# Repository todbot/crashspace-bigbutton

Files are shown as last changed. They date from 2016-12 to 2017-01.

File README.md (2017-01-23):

# crashspace-bigbutton



Firmware and schematics for the [CrashSpace](https://blog.crashspace.org/)
"BigButton" hardware interface to https://crashspacela.com/sign/

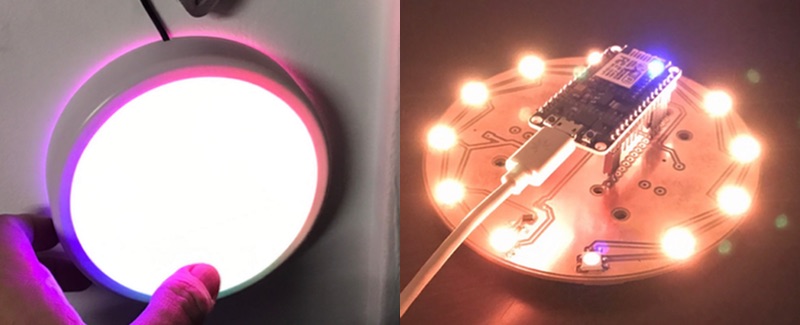
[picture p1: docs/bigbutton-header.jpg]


At [CrashSpace](https://blog.crashspace.org/) we have a publicly-viewable
"sign" at https://crashspacela.com/sign/ to let members know when the
space is open. This sign page is updated by a big button in the front
room.  Press it, the sign webpage updates, and you've promised to be
in the space for an hour.

This repo is documentation of the new BigButton hardware that was installed
at CrashSpace in Jan 2017.

## Table of Contents

* [Functionality](#functionality)
* [In use](#in-use)
* [Implementation](#implementation)
 * [Implementation - Hardware](#implementation---hardware)
    * [Converting 3v3 ESP8266 output for WS2812 / Neopixel  LEDs](#converting-3v3-esp8266-output-for-ws2812--neopixel--leds)
    * [Othermill design considerations](#othermill-design-considerations)
 * [Implementation - Firmware](#implementation---firmware)
    * [ArduinoJson is awesome](#arduinojson-is-awesome)
    * [CrashSpace sign server JSON API](#crashspace-sign-server-json-api)

## Functionality

* The BigButton consists of a pushbutton and a ring of LEDs
* The user pushes the button to signify they're at the space
* The LED ring displays whether or not CrashSpace is "open" or "closed"
* The LED ring visually shows a count down from 60 minutes,
  giving a rough indication of time left
* Pushing the button sends an HTTP request to the CrashSpace "sign" server
   at https://crashspacela.com/sign/
* (new!) The button periodically fetches a JSON feed from the
  sign server, getting time left and whether space is open or not.
  This allows for multiple buttons.

## In use

  * Button is pulsing ORANGE: CrashSpace is closed
  * Push Button.  Button spins a RAINBOW for a second or two, then
  * Button is pulsing TEAL: CrashSpace is open
  * Button counts down my extinguishing TEAL LEDs in an arc
  * Button flashing RED: Internet is down

## Implementation

The original BigButton implementation was an Arduino Uno with WS2812 LEDs inside a
large taplight tied to a Linux netbook for WiFi connectivity.
An upgrade button created several years late used an early version of the
Particle Photon Internet Button kit in a custom 3d printed enclosure.

This version of BigButton uses an
[ESP82166 Wemos D1 mini](https://www.wemos.cc/product/d1-mini.html)
WiFi board mounted to a custom carrier board containing 12 WS2812 LEDs.
It uses the [ESP8266 Arduino core](https://github.com/esp8266/Arduino/)
to run an Arduino sketch.

### Implementation - Hardware

The hardware implementation is pretty straight forward.
The Wemos D1 mini ESP8266 board does all the work.
The input is a single button and the output is a string of WS2812 LEDs.

The schematic and layout for the carrier board is:

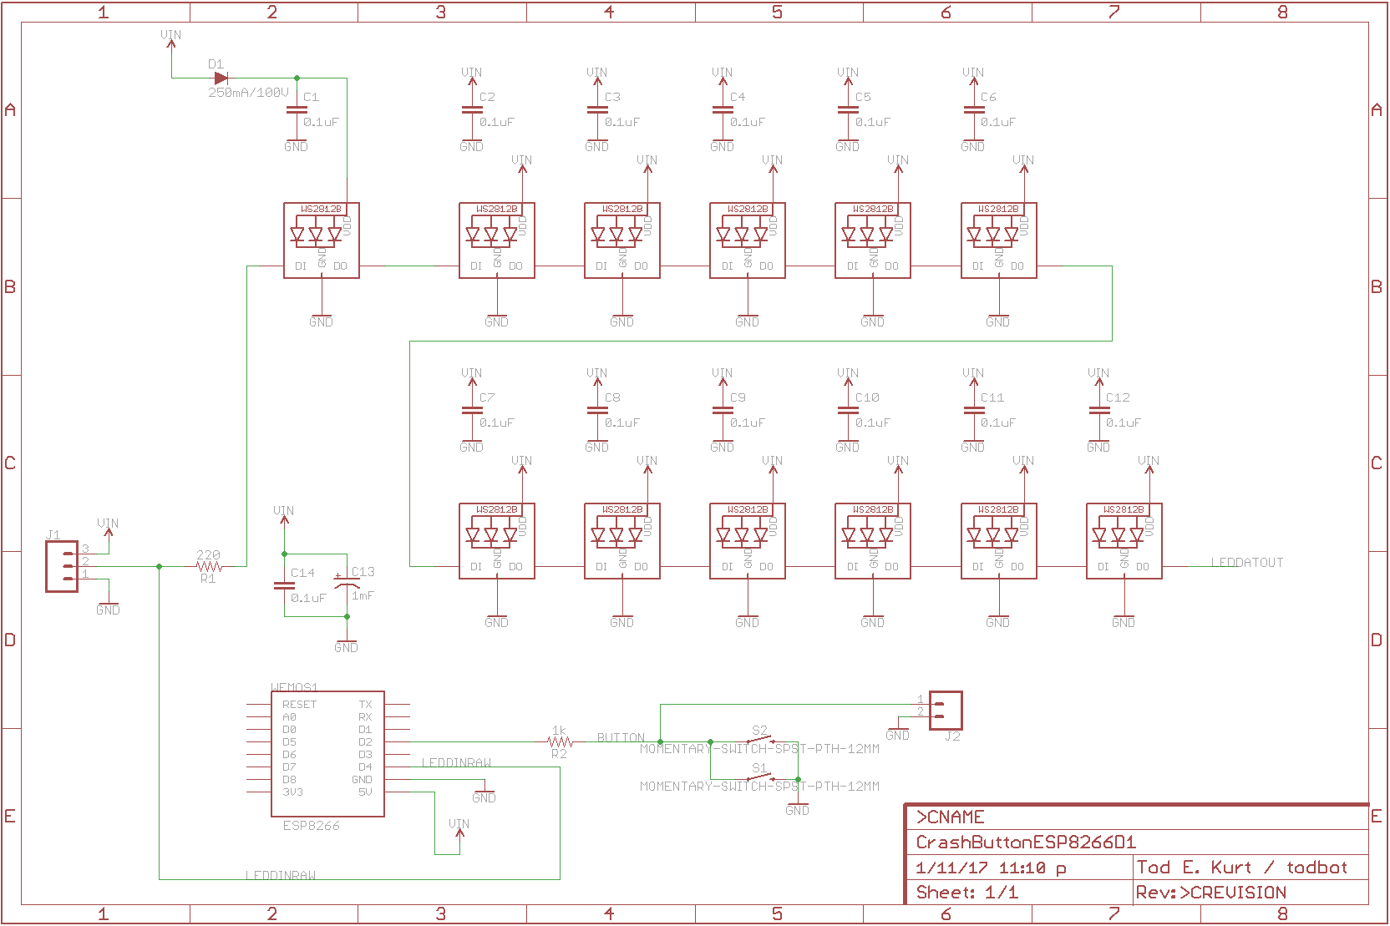
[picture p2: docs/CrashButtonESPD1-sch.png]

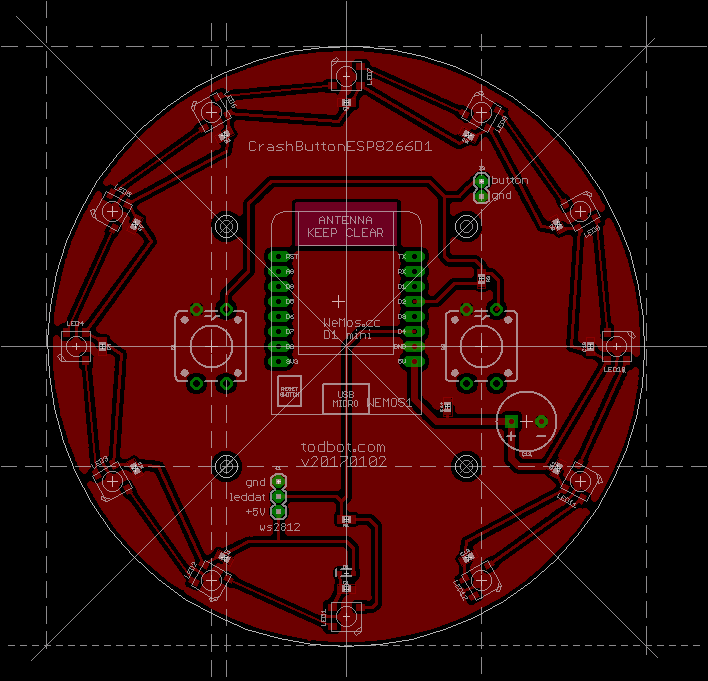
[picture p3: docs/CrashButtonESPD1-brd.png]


Eagle format versions of these are in the [schematic](./schematic) folder.

#### Converting 3v3 ESP8266 output for WS2812 / Neopixel  LEDs

One interesting thing about the schematic how the ESP8266 (a 3v3 device)
manages to control 5V WS2812/Neopixel LEDs.  Some WS2812s can be driven by 3v3 logic HIGH, but it's iffy.  The standard solution is a level-shifter buffer to convert 3v3 HIGH to 5V HIGH.

The technique used on this board, however, is to create a "sacrificial" LED that powered not by 5V but by a stepped-down voltage from a standard signal diode
(with its 0.7V voltage drop).  This creates an approx. 4.3V power source that is high enough to drive the LED but brings its concept of logic HIGH (>70% of Vcc) down to what a 3v3 device will output.  Basically, we're building a
special intermediary power supply for a single LED.
The rest of the WS2812 LEDs are driven by 5V.

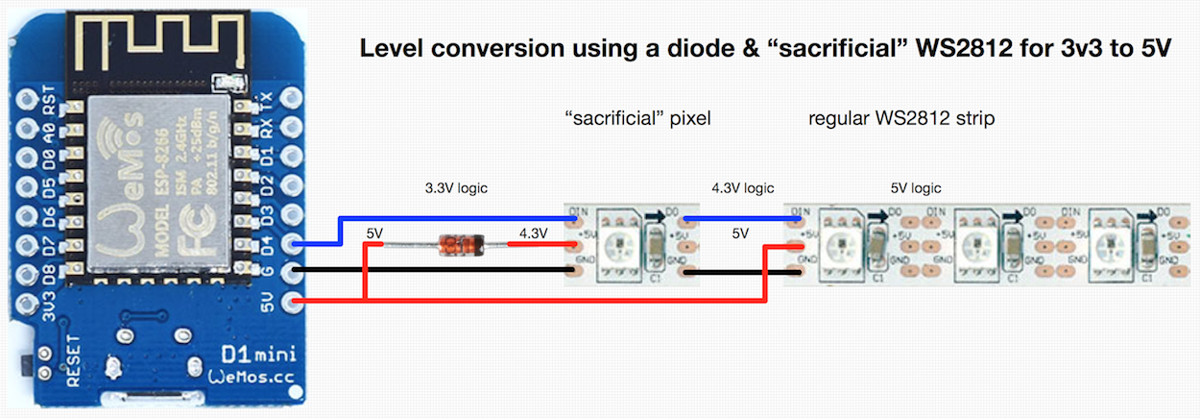
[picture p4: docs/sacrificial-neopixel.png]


#### Othermill design considerations

I wanted this board to be millable on an Othermill, so that meant adopting slightly different PCB design techniques.  There are a few reasons for this. For instance, because this board has no soldermask, I want to maximize spacing between copper traces.  Also, I would like to minimize the use of endmills smaller than 1/32" because they are fragile and take a long time to mill.  Thus, the techniques I use are:

* Increase trace width 16 mil (0.016")
* Add ground plane, set its Polygon->Isolate value to 32 mil (0.032")
* Single-sided only design (or minimize back-side traces)
* Space components out to enable easy soldering

The result is below. The Wemos D1 Mini ESP8266 board is mounted on the
backside of the board to minimize its impact on light output.  
The board is mounted on standoffs which are screwed into the modified
taplight. The taplight's switch is reused as the button input.

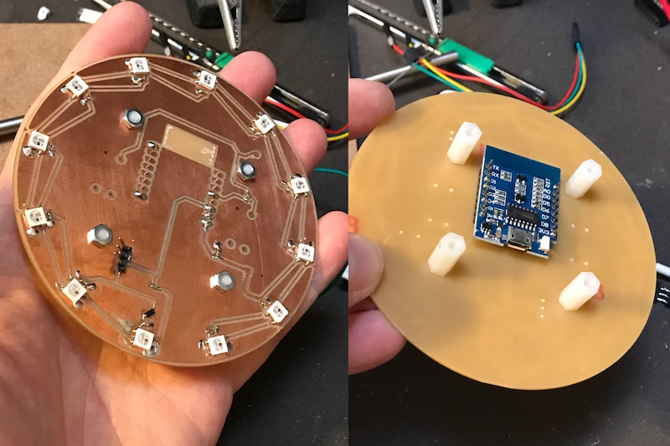
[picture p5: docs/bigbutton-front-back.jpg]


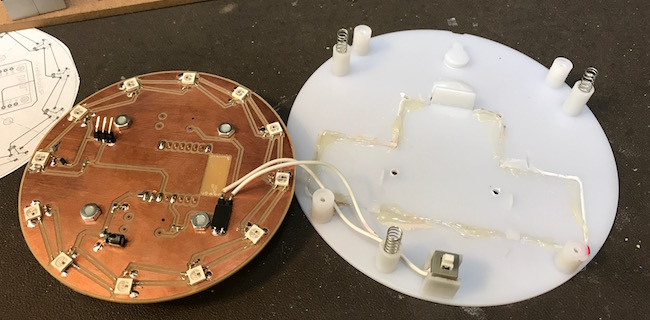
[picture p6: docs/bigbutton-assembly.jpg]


### Implementation - Firmware

The ESP8266 runs the ["CrashButtonESP"](./CrashButtonESP/) Arduino sketch.

#### ArduinoJson is awesome

The sketch relies on the ArduinoJson library.
With it you can easily parse and use JSON data structures.
And with its magical use of C++ operator-overloading you can have code
like this:

```c++
// jsonstr = '{"is_open":false,"minutes_left":-920.45,"button_presses":[]}'
JsonObject& root = jsonBuffer.parseObject(jsonstr);
bool is_open        = root["is_open"];
double minutes_left = root["minutes_left"];
```

#### CrashSpace sign server JSON API

To enable the button to report real open status
(and not just a dumb countdown), the sign server API at
https://crashspacela.com/sign/
has been updated with a JSON output mode.  There are two versions
of JSON output, picked with the `output` query arg:
* `jsonmin` - "minimal" version with just open status and minutes left
* `json`  - full version that gives a list of recent button presses

The Button uses the minimal one.  Both are shown below:

```json
% curl 'https://crashspacela.com/sign/?output=jsonmin'
{"is_open":false,"minutes_left":-920.45,"button_presses":[]}
```

```json
% curl 'https://crashspacela.com/sign/?output=json'
{
    "is_open": false,
    "minutes_left": -919.43333333333,
    "button_presses": [
        {
            "type": "update",
            "id": "crashbutton1",
            "msg": "Someone is at the space!",
            "diff_mins_max": 60,
            "description": "crashbutton1 - update - 60 mins.",
            "date": "Wed, 11 Jan 2017 21:38:03 -0800",
            "date_epoch": "1484199483"
        },
        {
            "type": "update",
            "id": "crashbutton1",
            "msg": "Someone is at the space!",
            "diff_mins_max": 60,
            "description": "crashbutton1 - update - 60 mins.",
            "date": "Wed, 11 Jan 2017 20:00:00 -0800",
            "date_epoch": "1484193600"
        },
        {
            "type": "update",
            "id": "crashbutton1",
            "msg": "Someone is at the space!",
            "diff_mins_max": 60,
            "description": "crashbutton1 - update - 60 mins.",
            "date": "Wed, 11 Jan 2017 19:16:26 -0800",
            "date_epoch": "1484190986"
        }
    ]
}
```

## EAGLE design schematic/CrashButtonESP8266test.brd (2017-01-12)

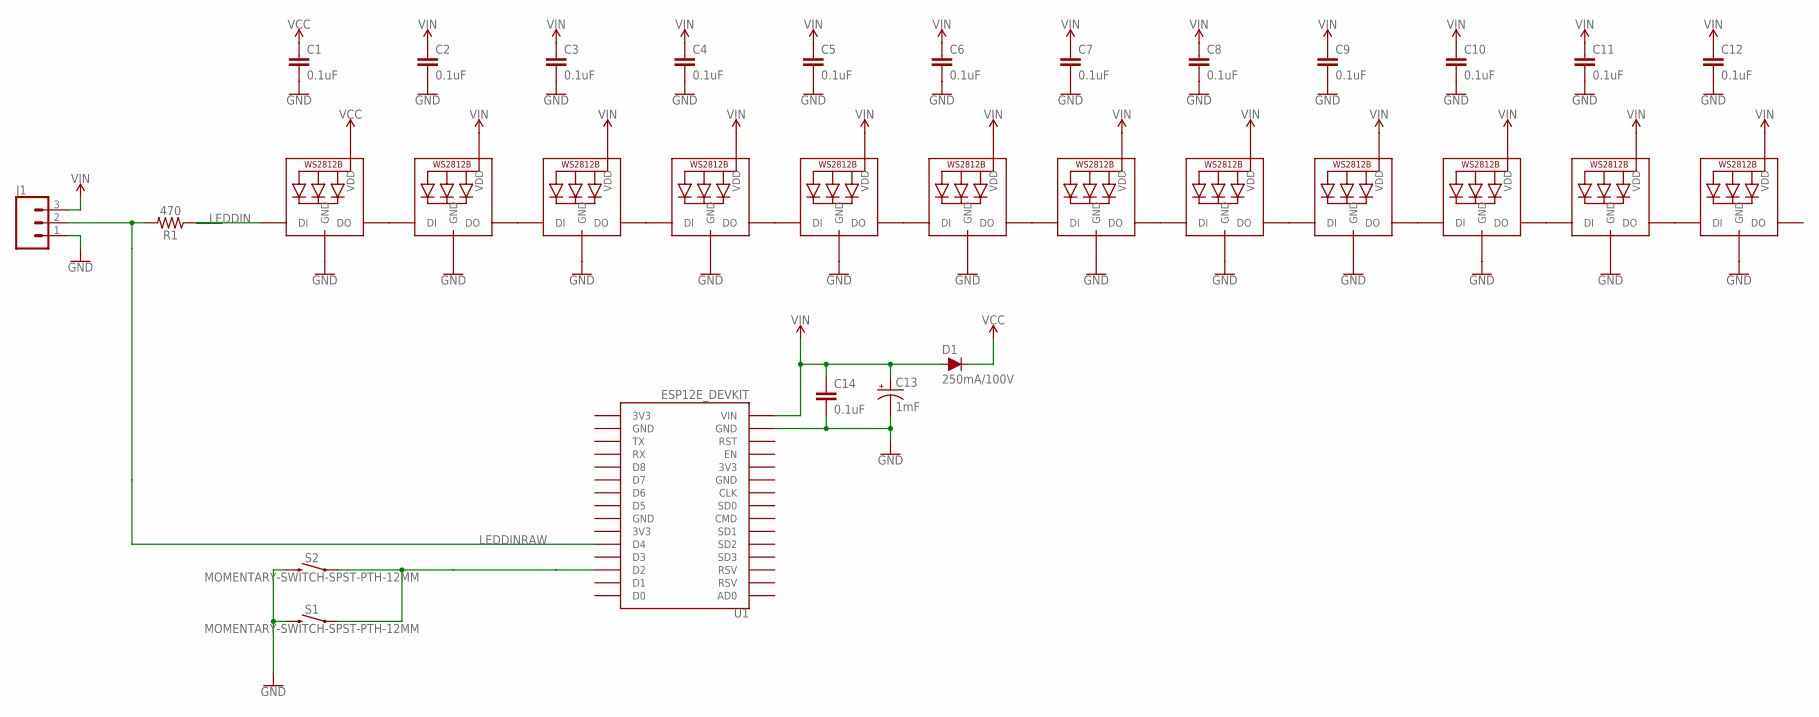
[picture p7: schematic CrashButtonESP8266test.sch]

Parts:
C1, C2, C3, C4, C5, C6, C7, C8, C9, C10, C11, C12, C14: 0.1uF; 0603
C13: 1mF; CPOL-RADIAL-5MM-10MM
D1: 250mA/100V; SOD-323
J1: CONN_03; 1X03
LED1, LED2, LED3, LED4, LED5, LED6, LED7, LED8, LED9, LED10, LED11, LED12: WS2812B5050; WS2812B
R1: 470; 0603
S1, S2: MOMENTARY-SWITCH-SPST-PTH-12MM; TACTILE_SWITCH_PTH_12MM
U1: ESP12E_DEVKIT

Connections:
GND: C1.2, C2.2, C3.2, C4.2, C5.2, C6.2, C7.2, C8.2, C9.2, C10.2, C11.2, C12.2, C13.-, C14.2, J1.1, LED1.3-GND (GND), LED2.3-GND (GND), LED3.3-GND (GND), LED4.3-GND (GND), LED5.3-GND (GND), LED6.3-GND (GND), LED7.3-GND (GND), LED8.3-GND (GND), LED9.3-GND (GND), LED10.3-GND (GND), LED11.3-GND (GND), LED12.3-GND (GND), S1.3 (2), S2.3 (2), U1.GND@1 (GND)
LEDDIN: LED1.4-DIN (DI), R1.1
LEDDINRAW: J1.2, R1.2, U1.D4
unnamed: LED1.2-DOUT (DO), LED2.4-DIN (DI)
unnamed: LED2.2-DOUT (DO), LED3.4-DIN (DI)
unnamed: LED3.2-DOUT (DO), LED4.4-DIN (DI)
unnamed: LED4.2-DOUT (DO), LED5.4-DIN (DI)
unnamed: LED5.2-DOUT (DO), LED6.4-DIN (DI)
unnamed: LED6.2-DOUT (DO), LED7.4-DIN (DI)
unnamed: LED8.2-DOUT (DO), LED9.4-DIN (DI)
unnamed: LED9.2-DOUT (DO), LED10.4-DIN (DI)
unnamed: LED10.2-DOUT (DO), LED11.4-DIN (DI)
unnamed: S1.1, S2.1, U1.D2
unnamed: LED7.2-DOUT (DO), LED8.4-DIN (DI)
unnamed: LED11.2-DOUT (DO), LED12.4-DIN (DI)
VCC: C1.1, D1.C, LED1.1-VDD (VDD)
VIN: C2.1, C3.1, C4.1, C5.1, C6.1, C7.1, C8.1, C9.1, C10.1, C11.1, C12.1, C13.+, C14.1, D1.A, J1.3, LED2.1-VDD (VDD), LED3.1-VDD (VDD), LED4.1-VDD (VDD), LED5.1-VDD (VDD), LED6.1-VDD (VDD), LED7.1-VDD (VDD), LED8.1-VDD (VDD), LED9.1-VDD (VDD), LED10.1-VDD (VDD), LED11.1-VDD (VDD), LED12.1-VDD (VDD), U1.VIN

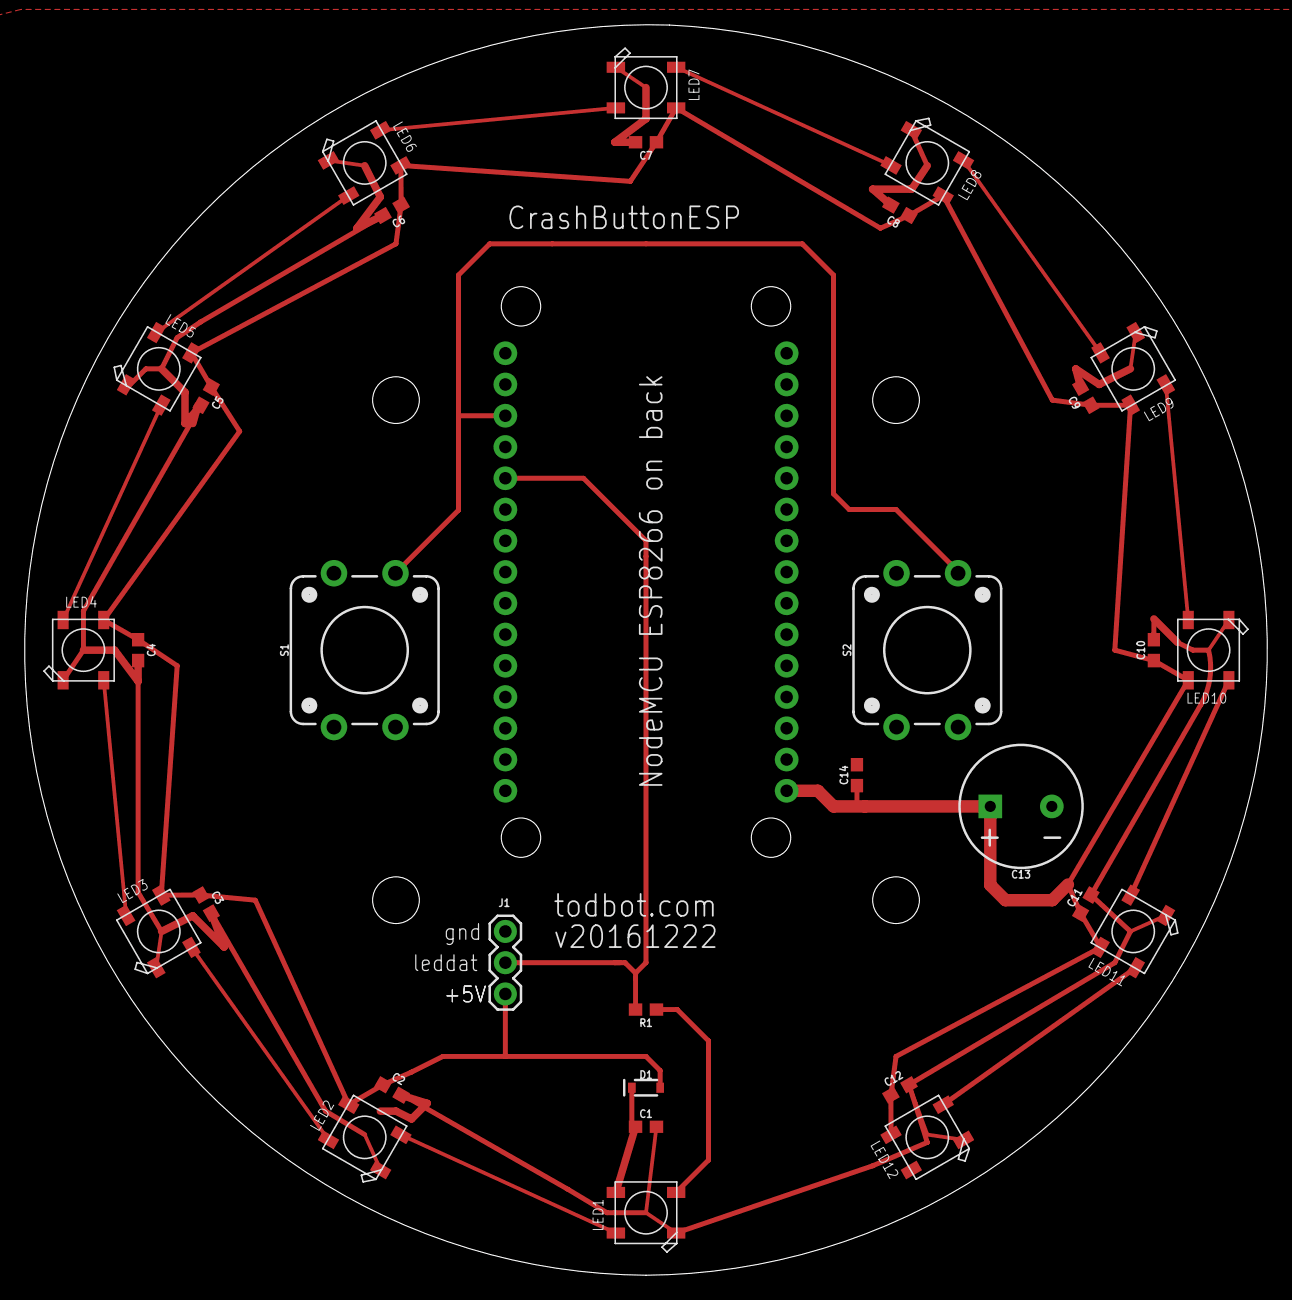
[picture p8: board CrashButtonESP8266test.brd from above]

Board: 2 copper layers, 101.0 x 101.6 mm, 32 parts (1 on the bottom side), 17 nets.

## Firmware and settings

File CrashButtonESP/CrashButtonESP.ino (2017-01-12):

/**
 *  CrashButtonESP - ESP8266-based BigButton for CrashSpace
 *
 *  Tod E. Kurt / http://todbot.com/
 *  
 *  Set Board to be "Wemos D1 R2 & mini"
 *  
 *  Requires libraries:
 *  - FastLED 3.1+ - https://github.com/FastLED/FastLED
 *  - ArduinoJson - https://github.com/bblanchon/ArduinoJson
 *  - ESP8266 Arduino core - https://github.com/esp8266/Arduino/
 *  
 **/

#include <Arduino.h>

#include <ESP8266WiFi.h>
#include <ESP8266WiFiMulti.h>
#include <ESP8266HTTPClient.h>
#include <Ticker.h>  // part of ESP8266 Arduino core

//#define FASTLED_ALLOW_INTERRUPTS 0
#define FASTLED_ESP8266_RAW_PIN_ORDER
#include <FastLED.h>
FASTLED_USING_NAMESPACE

#include <ArduinoJson.h>

#include "CrashButtonConfig.h"


// What mode are we in?  These are the allowed ones
typedef enum ButtonModes {
    MODE_UNKNOWN = 0,
    MODE_STARTUP,      // not joined AP yet, 
    MODE_CLOSED,       // "closed" button hasn't been pressed in a while, color: yellow 
    MODE_PRESSED,      // user pressed button, but before app has fetched state
    MODE_PRESSED_GOOD, // user pressed button, but before app has fetched state
    MODE_OPEN,         // shows current open time 
    MODE_ERROR         // error of some kind, flash error, color: red
} ButtonMode;

typedef enum LedModes {
    MODE_OFF = 0,
    MODE_PRESET,
    MODE_SOLID,
    MODE_SINELON,
    MODE_BREATHE,
    MODE_SECTOR,
    MODE_SECTORBREATHE,
    MODE_RAINBOW
} LedMode;

const int rainbowTime = 5 * 1000;  // duration of rainbow when pressing button

const int fetchMillis = 15 * 1000;  // how often API URL is checked
uint32_t lastFetchMillis = 0;

const uint32_t buttonCheckMillis = 60 * 1000; // min time between valid presses
uint32_t lastButtonCheckTime;
int lastButtonState; // state of last button (if using pressIsToggle)
uint32_t buttonPressTime = 0;

const uint8_t ledUpdateMillis = 50; // how often LEDs are updated

int badCount;
int maxBadCount = 5;    // how many bad events to become an error light
const uint32_t badMillis = 30 * 1000; // time between bad checks 
uint32_t lastBadMillis = 0;

// args for ledMode, basically, hmmm.
uint8_t ledHue = 0; // rotating "base color" used by many of the patterns
int ledSpeed = 100;
int ledCnt = NUM_LEDS;
int ledRangeL = 0;
int ledRangeH = 255;

CRGB leds[NUM_LEDS];

ButtonMode buttonMode = MODE_STARTUP;
LedMode ledMode = MODE_OFF;

Ticker ledticker;
ESP8266WiFiMulti WiFiMulti;


//
void setup()
{
    Serial.begin(115200);
    //Serial.setDebugOutput(true);
    //WiFi.disconnect(true);   // delete old config
    //WiFi.setAutoConnect( false );
 
    Serial.println("\nCrashButtonESP: " BUTTON_ID );
    delay(1500);    
    Serial.println("WiFi config:");
    WiFi.printDiag(Serial);

    pinMode( BUTTONPIN, INPUT_PULLUP);
    lastButtonState = digitalRead( BUTTONPIN );
    
    FastLED.addLeds<WS2812, LEDPIN, GRB>(leds, NUM_LEDS).setCorrection(TypicalLEDStrip);
    FastLED.setBrightness( brightnessDefault );
    fill_solid(leds, NUM_LEDS, CRGB(55, 0, 55));
    FastLED.show();
    
    for (uint8_t t = 4; t > 0; t--) {
        Serial.printf("[setupa] waiting %d...\n", t);
        Serial.flush();
        delay(800);
    }
    
    WiFiMulti.addAP(wifiSSID, wifiPasswd);
    
    ledticker.attach_ms( ledUpdateMillis, ledUpdate );

    Serial.println("[setup] done");
}

//
void loop()
{
    // wait for WiFi connection
    int rc = WiFiMulti.run();
    if ( (rc == WL_CONNECTED) ) {
        fetchJson();
    } 
    else {
        badCount++;
        Serial.print("WiFi not connected: "); Serial.println(rc);
        WiFi.printDiag(Serial);
        delay(1000); // delay still services background tasks for WiFi connect
    }
    
}

// Convert app state to LED commands
void buttonModeToLedMode() 
{
    if( buttonMode == MODE_STARTUP ) { 
        ledHue = 192; 
        ledMode = MODE_BREATHE;
        ledSpeed = 100;
        ledRangeL = 0;
        ledRangeH = 155;
    }
    else if( buttonMode == MODE_CLOSED ) {
        ledHue = 64; // yellow
        ledMode = MODE_BREATHE;
        ledCnt = NUM_LEDS;
        ledSpeed = 15;
        ledRangeL = 100;
        ledRangeH = 255;
    }
    else if( buttonMode == MODE_PRESSED ) { 
        ledMode = MODE_RAINBOW;
        ledCnt = NUM_LEDS;
        ledSpeed = millis() / 5;
        if( !buttonPressTime ) { 
            buttonPressTime = millis();
        } else {  // HACK FIXME: this whole buttonMode to ledMode idea not very good
            if( (millis() - buttonPressTime) > rainbowTime ) {
                //Serial.println("DOING THE HACK!");
                buttonMode = MODE_OPEN;
            }
        }
    }
    else if( buttonMode == MODE_PRESSED_GOOD ) { 
        ledMode = MODE_RAINBOW;
        ledCnt = NUM_LEDS;
        ledSpeed = millis() / 10;
    }
    else if( buttonMode == MODE_OPEN ) {
        ledHue = 128; // aqua
        ledMode = MODE_SECTORBREATHE;
        // ledCnt set elsewhere
        ledSpeed = 15;
        ledRangeL = 100;
        ledRangeH = 255;        
    }
    else if( buttonMode == MODE_ERROR ) {
        ledMode = MODE_BREATHE;
        ledHue = 0;
        ledCnt = NUM_LEDS;
        ledSpeed = 120;
        ledRangeL = 0;   // brightness low
        ledRangeH = 100; // brightness high
    }
}

// called periodically from Ticker
void ledUpdate()
{
    buttonCheck();
    
    buttonModeToLedMode();

    errorDetect();
    
    if( ledMode == MODE_OFF ) {
        fadeToBlackBy( leds, NUM_LEDS, 255);
    }
    else if( ledMode == MODE_SOLID ) {
        fill_solid( leds, ledCnt, CHSV(ledHue, 255, 255) );
    }
    else if( ledMode == MODE_SECTOR ) {
        fill_solid( leds, NUM_LEDS, 0 );
        fill_solid( leds, ledCnt, CHSV(ledHue, 255, 255) );
    }
    else if( ledMode == MODE_BREATHE ) {
        int breathe = beatsin8( ledSpeed, ledRangeL, ledRangeH);
        fill_solid( leds, NUM_LEDS, 0 );
        fill_solid( leds, ledCnt, CHSV(ledHue, 255, breathe) );
    }
    else if( ledMode == MODE_SECTORBREATHE ) { 
        int breathe = beatsin8( ledSpeed, ledRangeL, ledRangeH);        
        fill_solid( leds, NUM_LEDS, 0 );
        fill_solid( leds, ledCnt, CHSV(ledHue, 255, breathe) );
        if( ledCnt < NUM_LEDS ) { 
            leds[ledCnt] = CHSV(64, 255, breathe); //CRGB(breathe,breathe,breathe);
        }
    }
    else if ( ledMode == MODE_SINELON ) {
        // a colored dot sweeping back and forth, with fading trails
        fadeToBlackBy( leds, NUM_LEDS, 10);
        int pos = beatsin16(13, 0, NUM_LEDS);
        leds[pos] += CHSV( ledHue, 255, 255);
    }
    else if( ledMode == MODE_RAINBOW ) { 
//        fill_rainbow( leds, ledCnt, millis()/5, 255 / ledCnt );
        fill_rainbow( leds, ledCnt, ledSpeed, 255 / ledCnt ); // 255/ledCnt means rainbow oroboros itself
    }
    else if( ledMode == MODE_PRESET ) {
        // do nothing
    }

    FastLED.show();
}

// check our button
void buttonCheck()
{
    uint32_t now = millis();   
    
    int b = digitalRead( BUTTONPIN );
    int lastb = (pressIsToggle) ? lastButtonState : LOW;
    lastButtonState = b; // save current button state
    if( b == lastb ) {
        return;  // not pressed
    }
    
    buttonMode = MODE_PRESSED;
    buttonPressTime = 0;
    
    if ( (now - lastButtonCheckTime) > buttonCheckMillis || (now < buttonCheckMillis) ) {
        lastButtonCheckTime = now;
        buttonMode = MODE_PRESSED_GOOD;
        lastFetchMillis -= fetchMillis; // signal: do fetch now
    }    
}

//
//
void fetchJson()
{
    uint32_t now = millis();
    if ( (now - lastFetchMillis) < fetchMillis ) {  // too soon
        return;
    }
    lastFetchMillis = now;

    uint32_t freesize = ESP.getFreeHeap();
    uint32_t chipId = ESP.getChipId();
    
    Serial.print(String("[http] @") + millis() +" id:"+ String( chipId, HEX ) +" freesize:"+ freesize +" mode:"+buttonMode );
    Serial.println(" IP: "+ WiFi.localIP().toString() +" SSID:"+ WiFi.SSID() +" RSSI:"+ WiFi.RSSI() +" dBm");

    HTTPClient http;
    bool isPressed = (buttonMode == MODE_PRESSED_GOOD);
    
    //http.begin(httpsurl, httpsfingerprint);   // configure traged server and url
    const char* httpurlbase = (isPressed) ? httpurl_press : httpurl_stat;
    
    String httpUrl = String(httpurlbase) +"&chipId="+ String(chipId,HEX) +"&secs="+ (millis()/1000) +"&bc="+ badCount;
    const char* httpurl = httpUrl.c_str();
    
    http.begin(httpurl);

    Serial.print("[http]: "); Serial.println(httpurl);
    // start connection and send HTTP header
    int httpCode = http.GET();

    // httpCode will be negative on error
    if (httpCode > 0) {
        // HTTP header has been sent and Server response header has been handled
        Serial.print("[http] response code: "); Serial.println(httpCode);

        // file found at server
        if ( httpCode == HTTP_CODE_OK ) {
            String payload = http.getString();
            bool goodresponse = handleJson( payload );
            if( !goodresponse ) {  badCount++;  }  // bad parse
        }
        else { 
            badCount++; // not a 200 response
        }
    }
    else {
        Serial.printf("[http] GET... failed, error: \n%s\n", http.errorToString(httpCode).c_str());
        badCount++;
    }

    http.end();
  
    delay(100); // FIXME: why is this here?
}

//
bool handleJson(String jsonstr)
{
    Serial.println(jsonstr);

    StaticJsonBuffer<200> jsonBuffer;
    JsonObject& root = jsonBuffer.parseObject(jsonstr);
    // Test if parsing succeeds.
    if (!root.success()) {
        Serial.println("parseObject() failed");
        return false;
    }

    bool is_open = root["is_open"];  // wow, ArduinoJson is a cool hack
    double minutes_left = root["minutes_left"];

//    Serial.print("is_open:" + is_open +", minutes_left:" + minutes_left);

    if ( minutes_left > 0 ) {
        minutes_left = (minutes_left > 60) ? 60 : minutes_left;
        ledCnt =   NUM_LEDS * minutes_left / 60;  // ranges from 0 - NUM_LEDS
//        Serial.print("ledCnt:" + ledCnt);
        buttonMode = MODE_OPEN;
    }
    else {
        buttonMode = MODE_CLOSED;
    }
    
    return true;
}

// accumulate badness, if too much, trigger error
void errorDetect()
{
    uint32_t now = millis();   
    if ( (now - lastBadMillis) < badMillis ) {  // too soon
        return;
    }
    lastBadMillis = now;
    
    Serial.printf("errorDetect: badCount:%d\n", badCount);
    
    if( badCount >= maxBadCount ) { 
        buttonMode = MODE_ERROR;  // signal error
    }
    
    // decay badcount
    // FIXME: maybe have some mechanism to allow badCount to decay faster with multiple good events?
    if( badCount > 0 ) { badCount--; }
}


// Confusing NodeMCU vs Mini D1 board notation aside:
// On both NodeMCU and D1 Mini boards, pin "D4" is GPIO2.
// FastLED tries to help out NodeMCU users by mapping Dx numbers to GPIO numbers
//  (e.g. '4' means NodeMCU D4 pin not GPIO 4 when NodeMCU board is selected)
// However, when WeMos D1 Mini board is selected, FastLED pin number is GPIO number (e.g. '2' means GPIO2 not D2)

/*
  NodeMCU has weird pin mapping.
  Pin numbers written on the board itself do not correspond to ESP8266 GPIO pin numbers. We have constants defined to make using this board easier:

  static const uint8_t D0   = 16;
  static const uint8_t D1   = 5;
  static const uint8_t D2   = 4;
  static const uint8_t D3   = 0;
  static const uint8_t D4   = 2;  NeoEsp8266Uart800KbpsMethod
  static const uint8_t D5   = 14;
  static const uint8_t D6   = 12;
  static const uint8_t D7   = 13;
  static const uint8_t D8   = 15;
  static const uint8_t D9   = 3;  NeoEsp8266Dma800KbpsMethod  // default, also UART RX
  static const uint8_t D10  = 1;


*/

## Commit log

2016-12-18 refactor to add ButtonModes
2016-12-19 circular layout
    [CrashButtonESP8266.brd, CrashButtonESP8266.sch]
2016-12-20 moved buttoncheck to ledticker, moved ledpin to D4 in case I want to use NeoPixelBus
    [CrashButtonESP8266.brd, CrashButtonESP8266.sch]
2016-12-20 made url configurable, added note aboute sacrificial LED
2016-12-20 moved ledticker to end of setup since it seemed to be causing crashes w/ FastLED
    [CrashButtonESP.ino]
2016-12-22 version with enough polygon isolate to be solderable when othermilled
    [CrashButtonESP8266.brd, CrashButtonESP8266.sch]
2016-12-30 added board that uses D1 mini style esp8266
    [CrashButtonESP8266D1.brd, CrashButtonESP8266D1.sch]
2017-01-01 added badCount tracking instead of immediately slam to error; also some cleanup
    [CrashButtonESP.ino]
2017-01-02 added button info to API query to help aid future diagnostics
2017-01-04 cleanup diag prints
2017-01-04 schematic updates
    [CrashButtonESP8266D1.brd, CrashButtonESP8266D1.sch]
2017-01-11 updated schematic
    [CrashButtonESP8266D1.brd, CrashButtonESP8266D1.sch]
2017-01-12 fixup construction lines
    [CrashButtonESP8266D1.brd]
2017-01-12 started on docs
    [CrashButtonESP8266test.brd, CrashButtonESP8266test.sch]

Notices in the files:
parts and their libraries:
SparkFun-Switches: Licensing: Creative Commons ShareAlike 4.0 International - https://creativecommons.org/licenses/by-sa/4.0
